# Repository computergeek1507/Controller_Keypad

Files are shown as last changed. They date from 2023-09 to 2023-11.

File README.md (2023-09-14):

# Copyright and Disclaimer
Copyright: Scott Hanson

This documentation describes Open Hardware and is licensed under the CERN Open Hardware License Version 2 - Strongly Reciprocal. (CERN-OHL-S)

You may redistribute and modify this documentation under the terms of the CERN OHL-S-v2 (https://ohwr.org/cern_ohl_s_v2.txt). This documentation is distributed WITHOUT ANY EXPRESS OR IMPLIED WARRANTY, INCLUDING OF MERCHANTABILITY, SATISFACTORY QUALITY AND FITNESS FOR A PARTICULAR PURPOSE. Please see the CERN OHL v2-S for applicable conditions

**Under CERN OHL-S-v2, derivative work must be publicly released as defined in subsection 3.3**

# Controller Keypad

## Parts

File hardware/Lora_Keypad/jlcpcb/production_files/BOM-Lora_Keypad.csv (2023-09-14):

Comment | Designator | Footprint | LCSC
~ | U2 | 3x4_keypad
Heltec_Wifi_LoRa_V1 | U1 | Heltec_WiFi_LoRa_V2
Debug | J1 | PinHeader_1x06_P2.54mm_Vertical

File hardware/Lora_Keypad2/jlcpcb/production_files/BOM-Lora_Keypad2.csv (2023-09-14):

Comment | Designator | Footprint | LCSC
4.7K | R1,R2 | R_0603_1608Metric | C23162

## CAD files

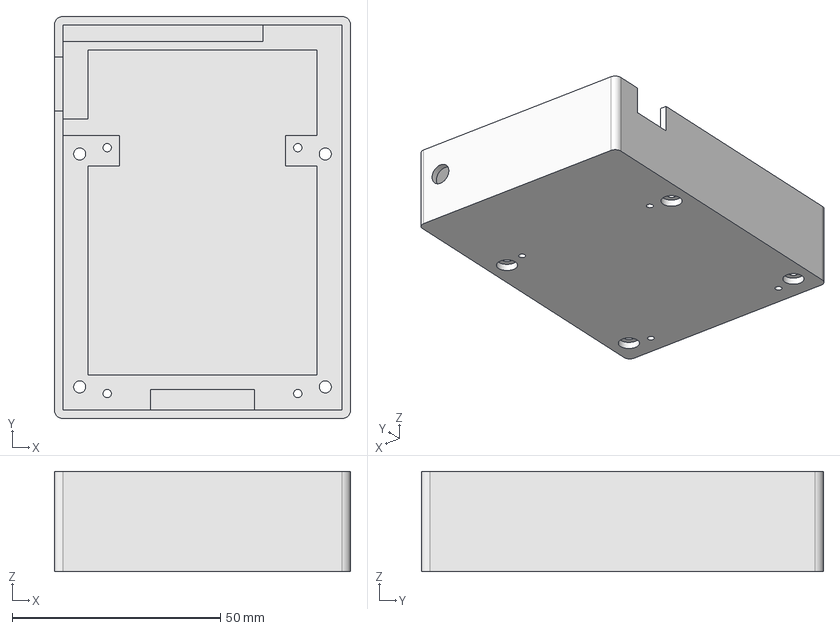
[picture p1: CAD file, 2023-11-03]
hardware/Lora_Keypad/case/case2.FCStd
71.0 x 96.4 x 24.0 mm

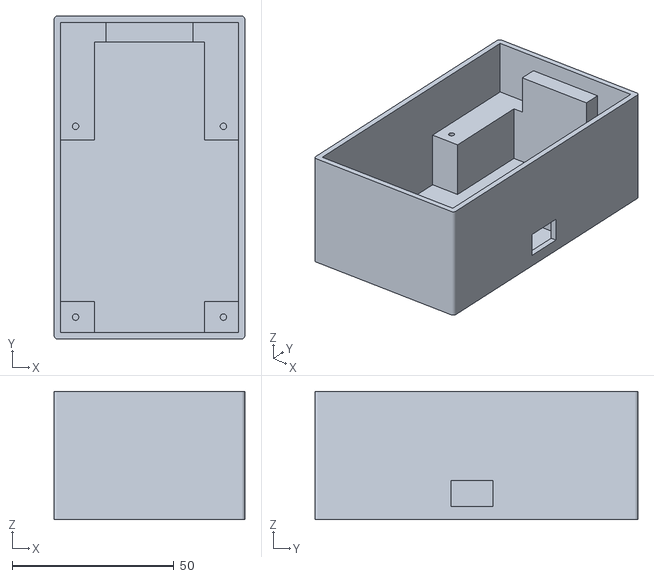
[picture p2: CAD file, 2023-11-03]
hardware/Lora_Keypad2/case/Case-bottom.stl
59.0 x 99.9 x 39.6

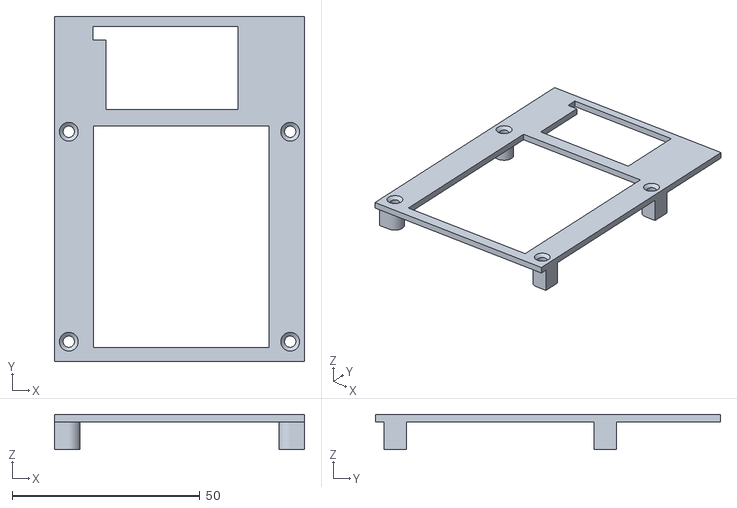
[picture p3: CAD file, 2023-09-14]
hardware/Lora_Keypad/case/case-Top.stl
66.5 x 91.9 x 9.40

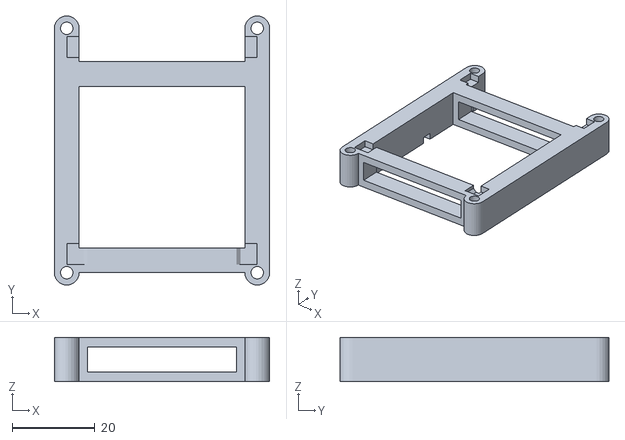
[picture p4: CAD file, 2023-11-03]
hardware/Lora_Keypad2/case/Case-spacer.stl
52.0 x 65.0 x 10.7

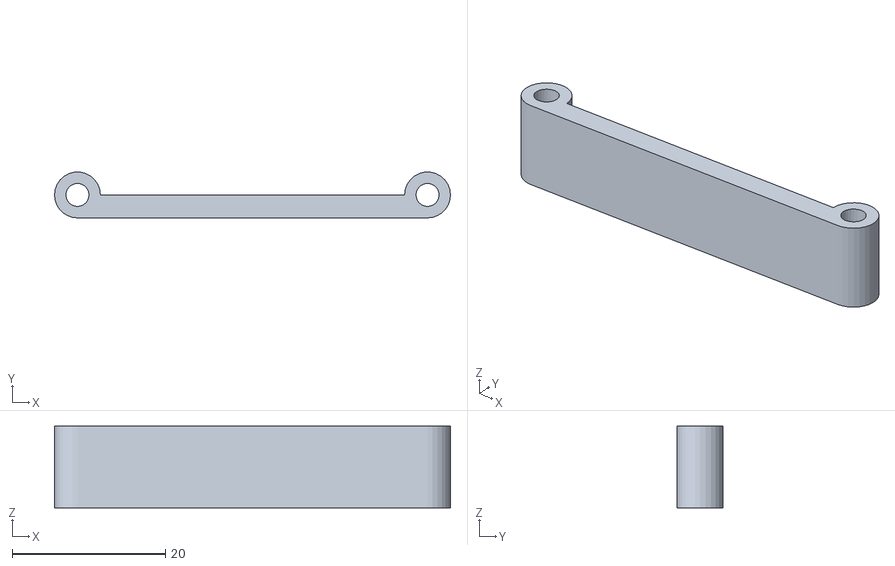
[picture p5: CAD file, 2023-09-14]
hardware/Lora_Keypad/case/case2-spacer.stl
51.7 x 5.98 x 10.7

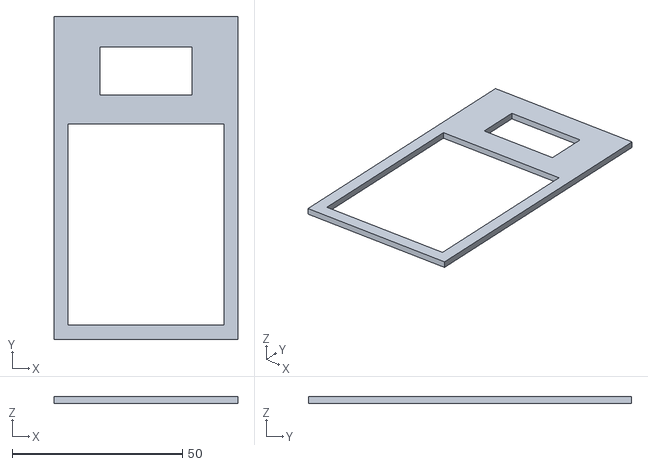
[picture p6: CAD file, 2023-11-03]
hardware/Lora_Keypad2/case/Case-top.stl
54.0 x 94.9 x 2.00

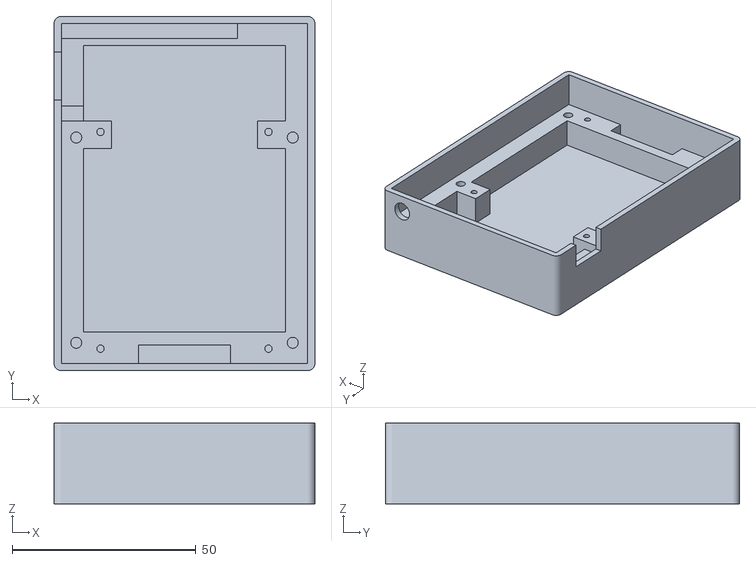
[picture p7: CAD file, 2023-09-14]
hardware/Lora_Keypad/case/case-Bottom.stl
71.0 x 96.4 x 22.0

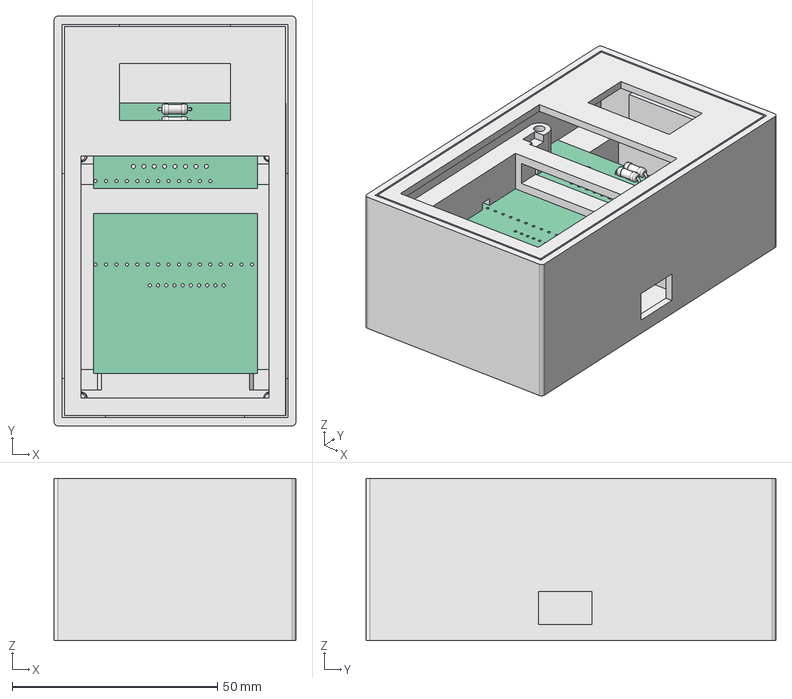
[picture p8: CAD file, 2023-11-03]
hardware/Lora_Keypad2/case/Case.FCStd
59.0 x 99.9 x 39.6 mm
bottom
Pcb_aefa
R3_R_Axial_DIN0207_L63mm_D25mm_P762mm_Horizontal_120a1ebcd147 x 2
R1_R_0603_1608Metric_9744cfa83997 x 2
top
spacer

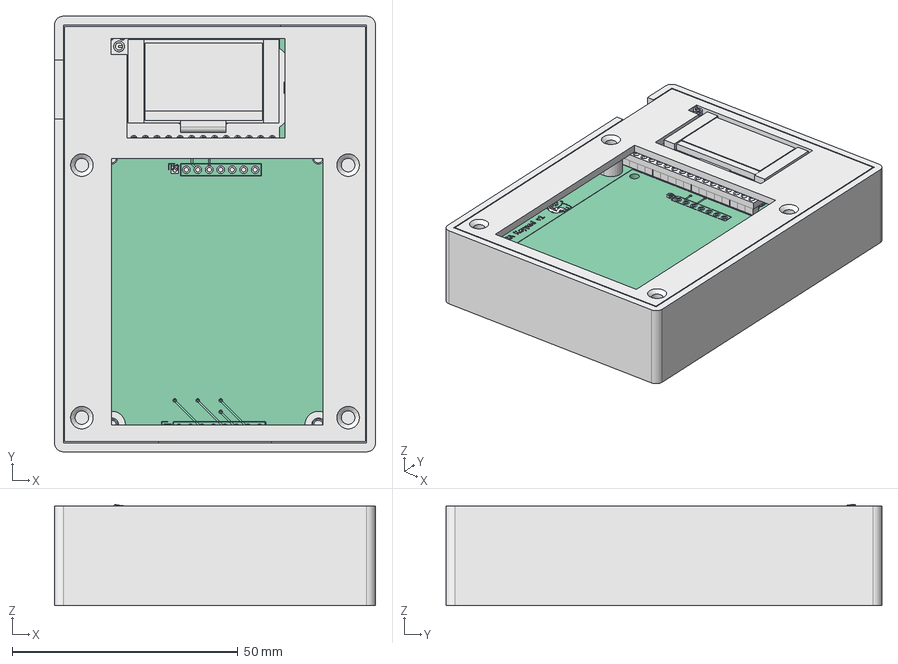
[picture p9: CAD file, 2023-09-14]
hardware/Lora_Keypad/case/case.FCStd
71.0 x 96.4 x 22.4 mm
Bottom
Pcb_8319
topPads_8319_cut
topTracks_8319
botPads_8319
botTracks_8319
topSilks_ac12
U1_ESP32 Heltec WIFI_6b2b8f31ec29
J1_PinHeader_1x06_P254mm_Vertical_01981719d589
Top
spacer

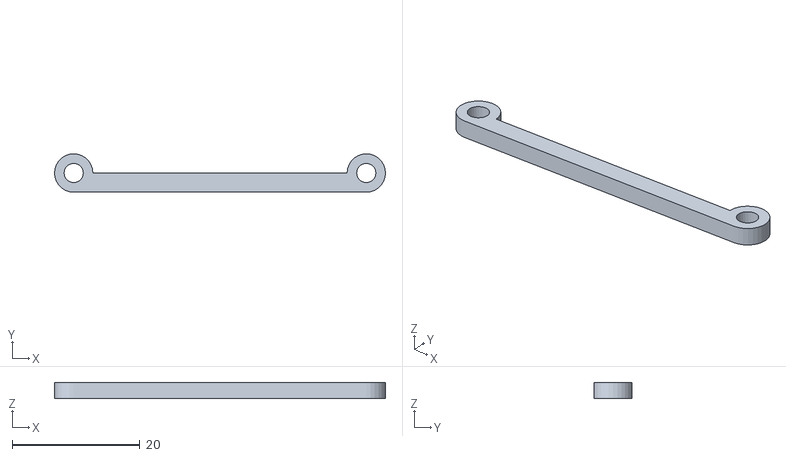
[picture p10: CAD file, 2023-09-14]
hardware/Lora_Keypad/case/case-spacer.stl
51.7 x 6.00 x 2.54

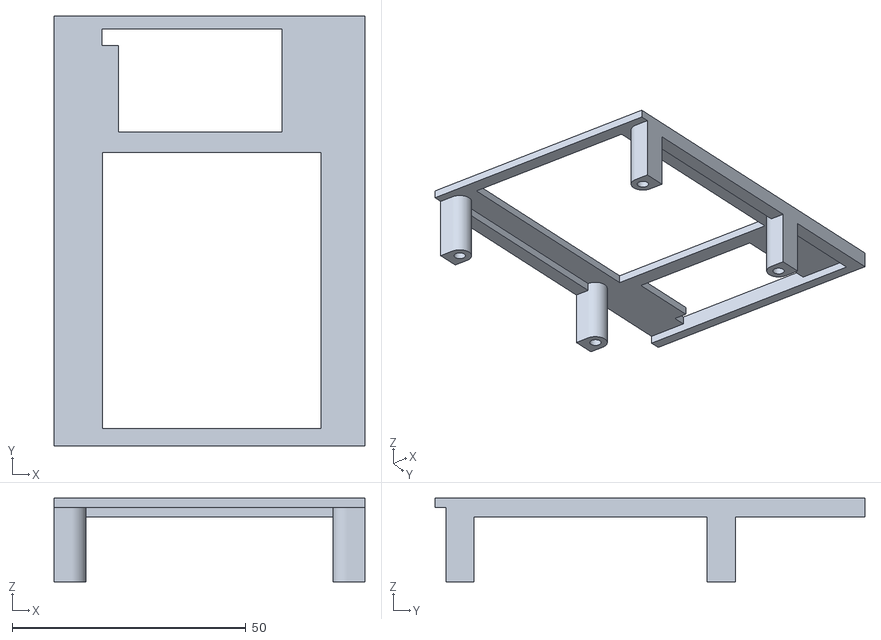
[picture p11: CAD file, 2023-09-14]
hardware/Lora_Keypad/case/case2-Top.stl
66.5 x 91.9 x 17.9

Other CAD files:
hardware/Lora_Keypad/case/case2-Bottom.stl

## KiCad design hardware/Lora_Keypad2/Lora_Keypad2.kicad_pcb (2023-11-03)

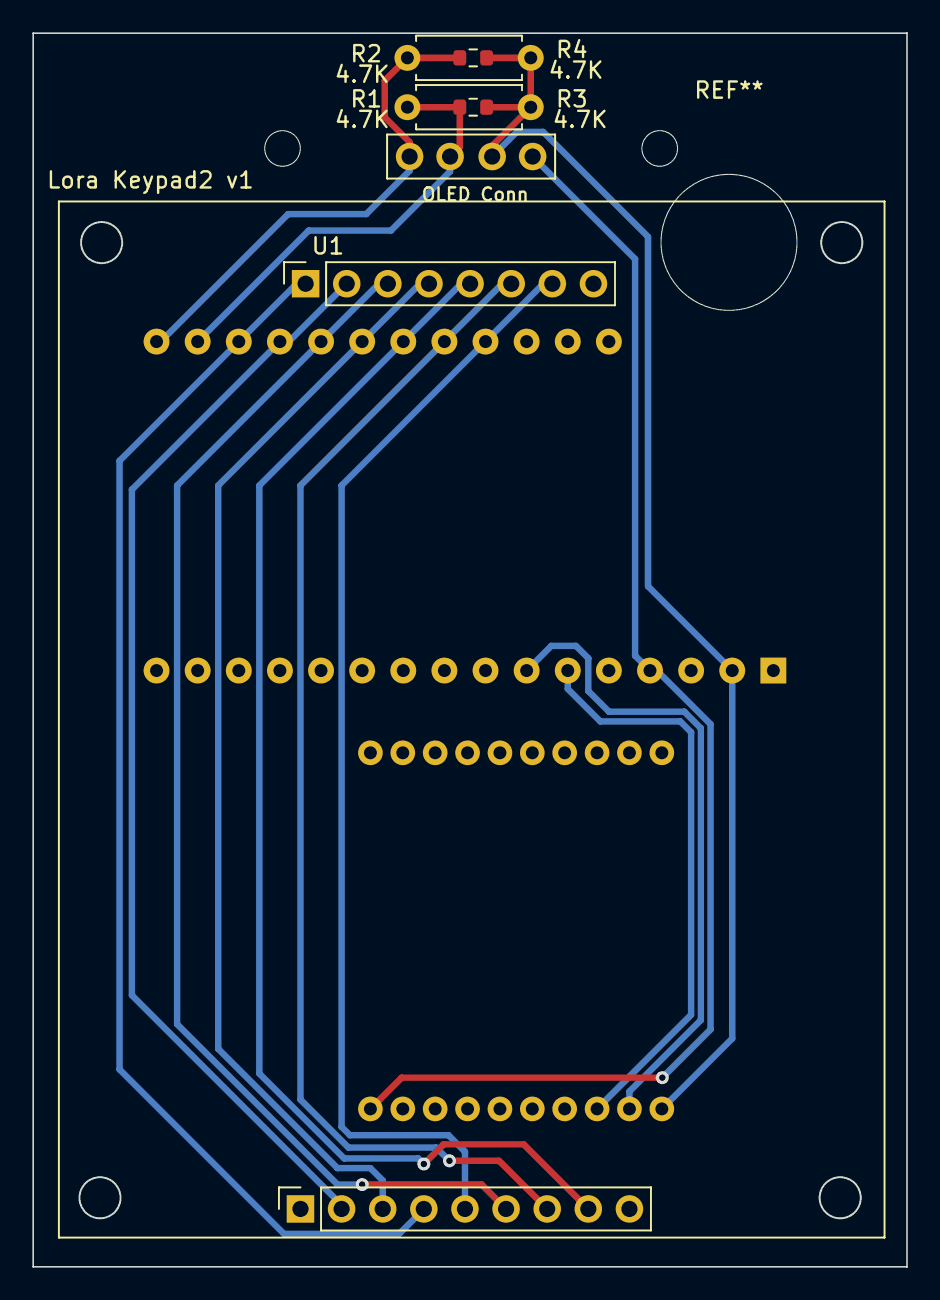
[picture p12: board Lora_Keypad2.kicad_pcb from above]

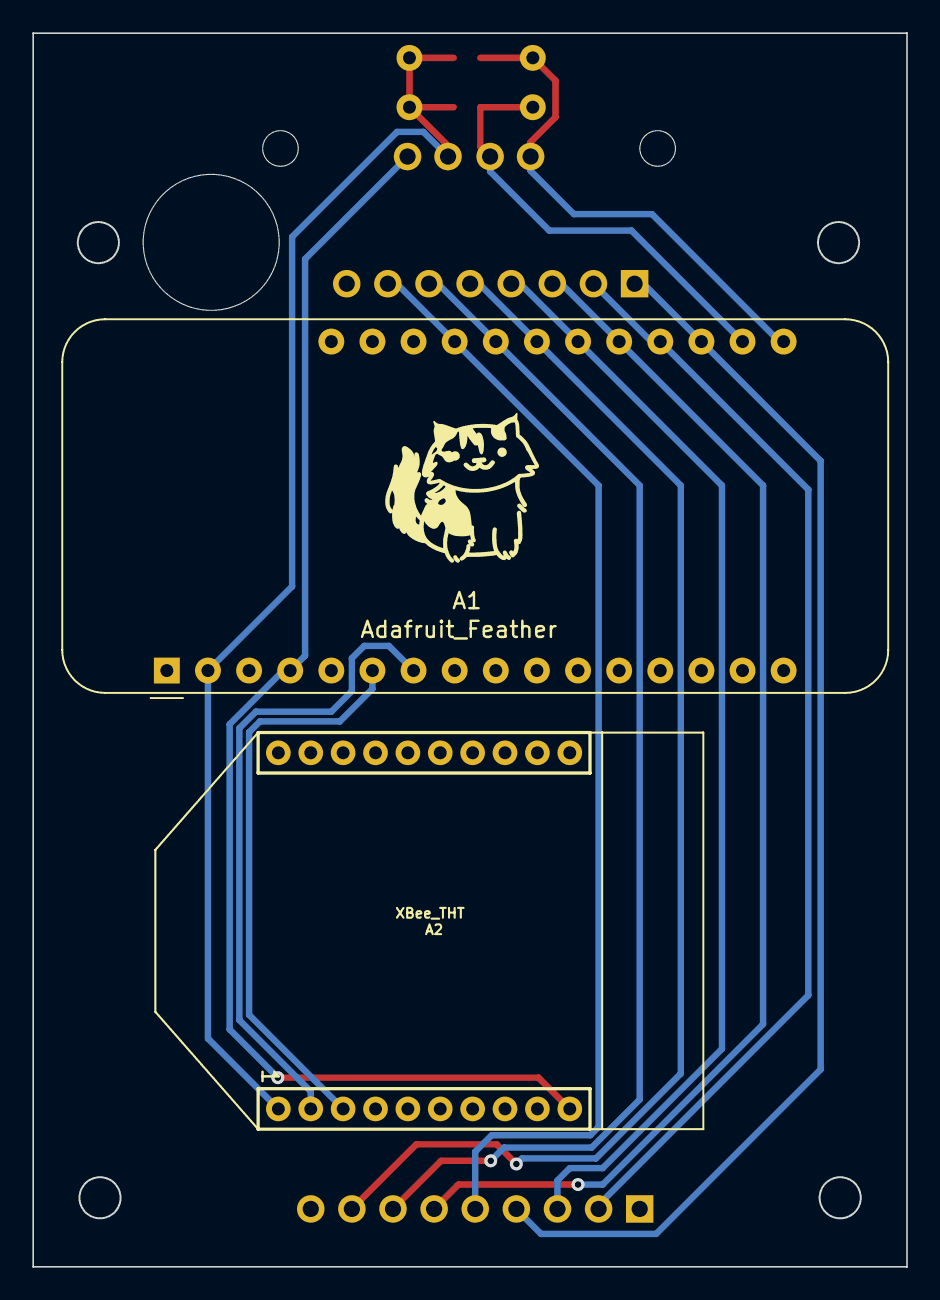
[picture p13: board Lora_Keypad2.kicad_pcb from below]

Board: 2 copper layers, 54.0 x 76.2 mm, 8 parts (2 on the bottom side), 13 nets.

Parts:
A1: Adafruit_Feather
A2: XBee_THT; XBEE
J1: OLED Conn; OLED-SSD1306-128X64-I2C-THT_2HOLE
R1, R2: 4.7K; R_0603_1608Metric
R3, R4: 4.7K; R_Axial_DIN0207_L6.3mm_D2.5mm_P7.62mm_Horizontal
U1: 3x4_keypad

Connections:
+3.3V: A1.2 (3V3), A2.1 (VCC), J1.3, R1.1, R2.1, R3.1, R4.1
C1: A1.19 (D0), U1.A1 (C1), U1.B4 (C1)
C2: A1.20 (D1), U1.A2 (C2), U1.B2 (C2)
C3: A1.21 (D2), U1.A3 (C3), U1.B6 (C3)
GND: A1.4 (GND), A2.10 (GND), J1.4
I2C_SCL: A1.18 (SCL), J1.2, R1.2, R3.2
I2C_SDA: A1.17 (SDA), J1.1, R2.2, R4.2
R1: A1.22 (D3), U1.A4 (R1), U1.B3 (R1)
R2: A1.23 (D4), U1.A5 (R2), U1.B8 (R2)
R3: A1.24 (D5), U1.A6 (R3), U1.B7 (R3)
R4: A1.25 (D6), U1.A7 (R4), U1.B5 (R4)
RX: A1.7 (A2), A2.2 (DOUT/DIO13)
TX: A1.6 (A1), A2.3 (DIN/~CONFIG/DIO14)

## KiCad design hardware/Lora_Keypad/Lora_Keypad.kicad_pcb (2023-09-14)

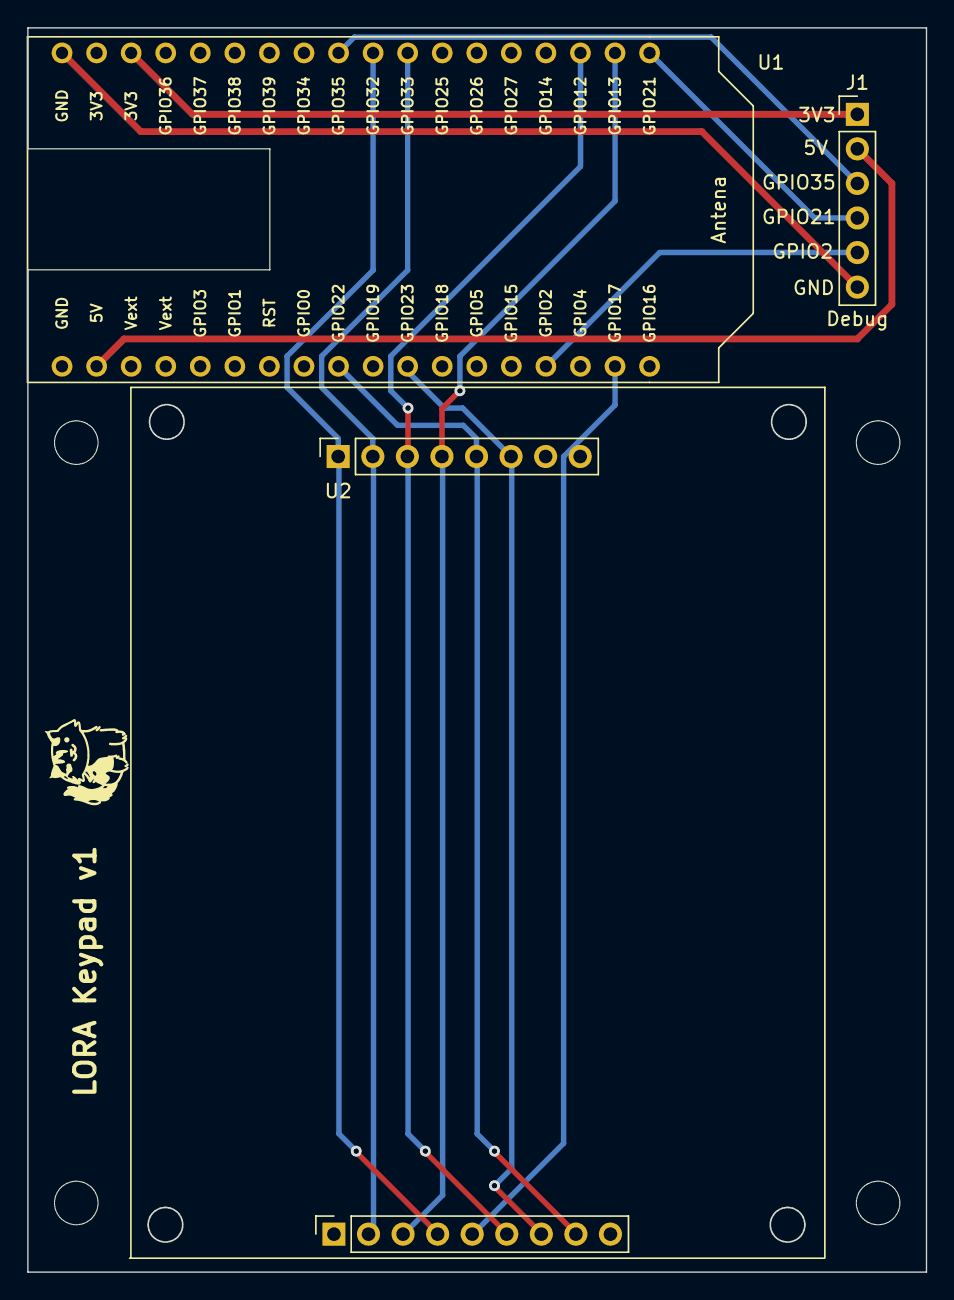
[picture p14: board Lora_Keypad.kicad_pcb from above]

Board: 2 copper layers, 66.0 x 91.4 mm, 7 parts (0 on the bottom side), 13 nets.

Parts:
H1, H2, H3, H4: MountingHole; MountingHole_3.2mm_M3
J1: Debug; PinHeader_1x06_P2.54mm_Vertical
U1: Heltec_Wifi_LoRa_V1; Heltec_WiFi_LoRa_V2
U2: 3x4_keypad

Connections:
+3.3V: J1.1, U1.34 (3V3)
+5V: J1.2, U1.2 (5V)
C1: U1.27 (LORA_DIO2/XTAL32/TOUCH9/ADC1_4/GPIO32), U2.A1 (C1), U2.B4 (C1)
C2: U1.26 (LORA_DIO1/XTAL32/TOUCH8/ADC1_5/GPIO33), U2.A2 (C2), U2.B2 (C2)
C3: U1.21 (TOUCH5/ADC2_5/GPIO12), U2.A3 (C3), U2.B6 (C3)
GND: J1.6, U1.36 (GND)
unnamed: J1.3, U1.28 (ADC1_7/GPIO35)
unnamed: J1.4, U1.19 (V_SPI_HD/SDA/GPIO21)
unnamed: J1.5, U1.15 (TOUCH2/HSPI_WP/ADC2_2/GPIO2)
R1: U1.20 (TOUCH4/ADC2_4/GPIO13), U2.A4 (R1), U2.B3 (R1)
R2: U1.9 (U0_RTS/V_SPI_WP/SCL/GPIO22), U2.A5 (R2), U2.B8 (R2)
R3: U1.11 (V_SPI_D/GPIO23), U2.A6 (R3), U2.B7 (R3)
R4: U1.17 (U2_TX/GPIO17), U2.A7 (R4), U2.B5 (R4)

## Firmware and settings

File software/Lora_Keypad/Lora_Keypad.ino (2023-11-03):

//#define USE_HELTEC_WIFI
#define USE_FEATHER_32

#if defined(USE_HELTEC_WIFI)
#define USE_LORA
//OLED pins
#define OLED_SDA 4
#define OLED_SCL 15 
#define LORA_TEXT 40 
#define WIFI_TEXT 50 
#endif

#if defined(USE_FEATHER_32)
//#define USE_XBEE
//OLED pins
#define OLED_SDA 23
#define OLED_SCL 22 
//#define LORA_TEXT -1 
#define WIFI_TEXT 40 
#endif

#include <Wire.h>
#include <Adafruit_GFX.h>
#include <Adafruit_SSD1306.h>

#include <FS.h>
#include <SPIFFS.h>
#include <ArduinoJson.h> 
#define JSON_CONFIG_FILE "/test_config.json"

#include <Keypad.h>

#include <Preferences.h>
Preferences preferences;

#include <HTTPClient.h>

#define WM_NOHELP
#include <WiFiManager.h> // https://github.com/tzapu/WiFiManager
WiFiManager wm;
WiFiManagerParameter custom_fpp_server("server", "FPP Master", "192.168.5.198", 15);
WiFiManagerParameter custom_subnet("subnet", "Controller Subnet ie'192.168.5'", "192.168.5", 11);
WiFiManagerParameter custom_playlist("playlist", "Playlist to start", "Main", 100);

#if defined(USE_LORA)
#include <SPI.h>
#include <LoRa.h>
//define the pins used by the LoRa transceiver module
#define SCK 5
#define MISO 19
#define MOSI 27
#define SS 18
#define RST 14
#define DIO0 26

//433E6 for Asia
//866E6 for Europe
//915E6 for North America
#define BAND 915E6
#endif
#define OLED_RST     -1 
#define SCREEN_WIDTH 128 // OLED display width, in pixels
#define SCREEN_HEIGHT 64 // OLED display height, in pixels

const byte ROWS = 4; // rows
const byte COLS = 3; // columns
//define the symbols on the buttons of the keypads
char keys[ROWS][COLS] = {
  {'1','2','3'},
  {'4','5','6'},
  {'7','8','9'},
  {'*','0','#'}
};

#if defined(USE_HELTEC_WIFI)
byte rowPins[ROWS] = {13, 22, 23, 17}; //connect to the row pinouts of the keypad
byte colPins[COLS] = {32, 33, 12}; //connect to the column pinouts of the keypad
#endif

#if defined(USE_FEATHER_32)
byte rowPins[ROWS] = {33, 27, 12, 13}; //connect to the row pinouts of the keypad
byte colPins[COLS] = {14, 32, 15}; //connect to the column pinouts of the keypad
#endif

//initialize an instance of class NewKeypad
Keypad keypad = Keypad( makeKeymap(keys), rowPins, colPins, ROWS, COLS );

String inputText;

String FPP_server;
String controller_subnet;
String playlist;

Adafruit_SSD1306 display(SCREEN_WIDTH, SCREEN_HEIGHT, &Wire, OLED_RST);

void setup() {
  //initialize Serial Monitor
  Serial.begin(115200);
  preferences.begin("LoRa-KEYPAD", false);

  FPP_server = preferences.getString("fpp_server", "192.168.5.198");
  if(!FPP_server.isEmpty()){
    custom_fpp_server.setValue(FPP_server.c_str(),15);
  }
  controller_subnet = preferences.getString("controller_subnet", "192.168.5");
  if(!controller_subnet.isEmpty()){
    custom_subnet.setValue(controller_subnet.c_str(),11);
  }
  playlist = preferences.getString("playlist", "Main");
  if(!playlist.isEmpty()){
    custom_playlist.setValue(playlist.c_str(),100);
  }

  //reset OLED display via software
  //pinMode(OLED_RST, OUTPUT);
  //digitalWrite(OLED_RST, LOW);
  //delay(20);
  //digitalWrite(OLED_RST, HIGH);

  //initialize OLED
  Wire.begin(OLED_SDA, OLED_SCL);
  if(!display.begin(SSD1306_SWITCHCAPVCC, 0x3c, false, false)) { // Address 0x3C for 128x32
    Serial.println(F("SSD1306 allocation failed"));
    for(;;); // Don't proceed, loop forever
  }
#if defined(USE_FEATHER_32)
  display.setRotation(2); //rotates text on OLED 1=90 degrees, 2=180 degrees
#endif  
  display.clearDisplay();
  display.setTextColor(WHITE);
  display.setTextSize(1);
  display.setCursor(0,0);
  display.print("Controller Keypad");
  display.display();

  Serial.println("Controller Keypad");

#if defined(USE_LORA)
  //SPI LoRa pins
  SPI.begin(SCK, MISO, MOSI, SS);
  //setup LoRa transceiver module
  LoRa.setPins(SS, RST, DIO0);
  
  if (!LoRa.begin(BAND)) {
    Serial.println("Starting LoRa failed!");
    while (1);
  }
  Serial.println("LoRa Initializing OK!");
  display.setCursor(0,10);
  display.print("LoRa Initializing OK!");
  display.display();
  delay(2000);
#endif
  //WiFi.mode(WIFI_STA); // explicitly set mode, esp defaults to STA+AP    
    
    //reset settings - wipe credentials for testing
    //wm.resetSettings();
    wm.addParameter(&custom_fpp_server);
    wm.addParameter(&custom_subnet);
    wm.addParameter(&custom_playlist);
    wm.setConfigPortalBlocking(false);
    wm.setParamsPage(true);
    std::vector<const char *> menuIds  = {"wifi","param","info","update"};
    wm.setMenu(menuIds);
    wm.setTitle("Controller Keypad");
    wm.setSaveParamsCallback(saveParamsCallback);

    wm.setSaveConfigCallback([&]()
    {
        display.clearDisplay();
        display.setCursor(0,0);
        display.println("Controller Keypad");
        display.setTextSize(1);
        if(WiFi.status() == WL_CONNECTED) {
          display.setCursor(0,20);
          display.print("Wifi Connected " + wm.getWiFiSSID(false));
          display.setCursor(0,30);
          display.print("Wifi IP " + WiFi.localIP().toString());
          display.display();
        }
    });

    //automatically connect using saved credentials if they exist
    //If connection fails it starts an access point with the specified name
    if(wm.autoConnect("KeypadAP")){
        display.setCursor(0,20);
        display.print("Wifi Connected " + wm.getWiFiSSID(false));
        display.setCursor(0,30);
        display.print("Wifi IP " + WiFi.localIP().toString());
        display.display();
        wm.startWebPortal();
    }
    else {
        display.setCursor(0,20);
        display.print("Wifi Portal started");
        display.setCursor(0,30);
        display.print(wm.getConfigPortalSSID());
        display.display();
    }
}

void loop() {
  char key1 = keypad.getKey();

  if (key1 != NO_KEY ){
    if(key1 == '*') {
      inputText = "";
      DisplayText();
    } else if(key1 == '#' ) {
      SendText();
      inputText = "";
    } else {
      inputText += key1;
      DisplayText();
    }
  }
  wm.process();
  delay(10);
}
void DisplayText()
{
  display.clearDisplay();
  display.setCursor(0,0);
  display.println("Controller Keypad");
  display.setTextSize(1);
  display.setCursor(0,30);
  display.print(inputText);
  display.display();
}

void SendText()
{
  Serial.print("Sending packet: ");
  Serial.println(inputText);
#if defined(USE_LORA)
  //Send LoRa packet to receiver
  LoRa.beginPacket();
  LoRa.print(inputText);
  LoRa.endPacket();
#endif
  display.clearDisplay();
  display.setCursor(0,0);
  display.println("Controller Keypad");
  #if defined(USE_LORA)
  display.setCursor(0,LORA_TEXT);
  display.setTextSize(1);
  display.print("LoRa packet sent:" + inputText);
  #endif
  //display.setCursor(0,30);
  //display.print(inputText);
  String message;
  if(SendWIFICommand(inputText, message)) {
    display.setCursor(0,WIFI_TEXT);
    display.setTextSize(1);
    display.print("WIFI packet sent:" + inputText);
  }else{
    display.setCursor(0,WIFI_TEXT);
    display.setTextSize(1);
    display.print("WIFI Failed " + message);
  }
  display.display();
}

void saveParamsCallback () {
  Serial.println("Get Params:");
  Serial.print(custom_fpp_server.getID());
  Serial.print(" : ");
  Serial.println(custom_fpp_server.getValue());
  FPP_server = custom_fpp_server.getValue();
  preferences.putString("fpp_server", FPP_server);

  Serial.println("Get Params:");
  Serial.print(custom_subnet.getID());
  Serial.print(" : ");
  Serial.println(custom_subnet.getValue());
  controller_subnet = custom_subnet.getValue();
  preferences.putString("controller_subnet", controller_subnet);

  playlist = custom_playlist.getValue();
  preferences.putString("playlist", playlist);
}

bool SendWIFICommand ( String number, String &message )
{
  if(WiFi.status() != WL_CONNECTED) {
    message = "Wifi Not Connected";
    return false;
  }
  if(FPP_server.isEmpty()){
    Serial.println("FPP_server is empty");
    message = "FPP_server is empty";
    return false;
  }

  if(controller_subnet.isEmpty()){
    Serial.println("controller_subnet is empty");
    message = "controller_subnet is empty";
    return false;
  }
  if(number == "400")
  {
    return StartPlaylist();
  }
  if(number == "500")
  {
    return StopPlaylist();
  }
  if(number == "501")
  {
    return StopGracefullyPlaylist();
  }
  if(number == "999")
  {
    return TurnOffAllController();
  }
  if(number == "998")
  {
    return TurnOnAllController();
  }
  //http://192.168.5.198/api/command/Controller%20Set%20Test%20Mode%20Off%20Auto/192.168.8.179
  return ToggleController(number);
}

bool ToggleController ( String number )
{
  //Controller Set All Test Mode Off
  //http://192.168.5.198/api/command/Controller%20Toggle%20Test%20Mode/192.168.8.179
  String url = "http://" + FPP_server + "/api/command/Controller%20Toggle%20Test%20Mode/" + controller_subnet + "." + number;
  return PostDataToFPP(url);
}

bool TurnOnAllController ()
{
  //Controller Set All Test Mode Off
  String url = "http://" + FPP_server + "/api/command/Controller%20Set%20All%20Test%20Mode%20On";
  return PostDataToFPP(url);
}

bool TurnOffAllController ()
{
  //Controller Set All Test Mode Off
  String url = "http://" + FPP_server + "/api/command/Controller%20Set%20All%20Test%20Mode%20Off";
  return PostDataToFPP(url);
}

bool StartPlaylist ()
{
  //Controller Set All Test Mode Off
  String url = "http://" + FPP_server + "/api/playlist/" + playlist + "/start";
  return PostDataToFPP(url);
}

bool StopPlaylist ()
{
  String url = "http://" + FPP_server + "/api/playlists/stop";
  return PostDataToFPP(url);
}

bool StopGracefullyPlaylist ()
{
  String url = "http://" + FPP_server + "/api/playlists/stopgracefully";
  return PostDataToFPP(url);
}

bool PostDataToFPP ( String httpRequestData )
{
  //http://192.168.5.198/api/command/Controller%20Set%20Test%20Mode%20Off%20Auto/192.168.8.179
  //WiFiClient client;
  HTTPClient http;
    
      // Your Domain name with URL path or IP address with path
      //http.begin(client, serverName);
    // Your Domain name with URL path or IP address with path
  http.begin(httpRequestData.c_str());

  // If you need Node-RED/server authentication, insert user and password below
  //http.setAuthorization("REPLACE_WITH_SERVER_USERNAME", "REPLACE_WITH_SERVER_PASSWORD");

  // Specify content-type header
  http.addHeader("Content-Type", "application/x-www-form-urlencoded");

  // Send HTTP POST request
  int httpResponseCode = http.GET();

  if (httpResponseCode>0) {
        Serial.print("HTTP Response code: ");
        Serial.println(httpResponseCode);
        String payload = http.getString();
        Serial.println(payload);
      }
      else {
        Serial.print("Error code: ");
        Serial.println(httpResponseCode);
      }
      // Free resources
      http.end();
  return httpResponseCode == 200;
}
/*
void saveConfigFile()
// Save Config in JSON format
{
  Serial.println(F("Saving configuration..."));
  
  // Create a JSON document
  StaticJsonDocument<512> json;
  json["testString"] = testString;
  json["testNumber"] = testNumber;
 
  // Open config file
  File configFile = SPIFFS.open(JSON_CONFIG_FILE, "w");
  if (!configFile)
  {
    // Error, file did not open
    Serial.println("failed to open config file for writing");
  }
 
  // Serialize JSON data to write to file
  serializeJsonPretty(json, Serial);
  if (serializeJson(json, configFile) == 0)
  {
    // Error writing file
    Serial.println(F("Failed to write to file"));
  }
  // Close file
  configFile.close();
}
 
bool loadConfigFile()
// Load existing configuration file
{
  // Uncomment if we need to format filesystem
  // SPIFFS.format();
 
  // Read configuration from FS json
  Serial.println("Mounting File System...");
 
  // May need to make it begin(true) first time you are using SPIFFS
  if (SPIFFS.begin(false) || SPIFFS.begin(true))
  {
    Serial.println("mounted file system");
    if (SPIFFS.exists(JSON_CONFIG_FILE))
    {
      // The file exists, reading and loading
      Serial.println("reading config file");
      File configFile = SPIFFS.open(JSON_CONFIG_FILE, "r");
      if (configFile)
      {
        Serial.println("Opened configuration file");
        StaticJsonDocument<512> json;
        DeserializationError error = deserializeJson(json, configFile);
        serializeJsonPretty(json, Serial);
        if (!error)
        {
          Serial.println("Parsing JSON");
 
          strcpy(testString, json["testString"]);
          testNumber = json["testNumber"].as<int>();
 
          return true;
        }
        else
        {
          // Error loading JSON data
          Serial.println("Failed to load json config");
        }
      }
    }
  }
  else
  {
    // Error mounting file system
    Serial.println("Failed to mount FS");
  }
 
  return false;
}
*/
